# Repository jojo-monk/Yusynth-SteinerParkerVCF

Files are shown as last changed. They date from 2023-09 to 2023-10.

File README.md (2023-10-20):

# Yusynth-SteinerParkerVCF
Adaptation du Yusynth [SteinerParkerVCF](http://yusynth.net/Modular/index_en.html) au format Eurorack
Testé et Fonctionnel

J'ai fait une petite erreur sur la sérigraphie du bouton Mode qui se trouvait du mauvais côté du bouton, mais c'est corrigé dans le fichier kicad.
J'ai ajouté un trimmer 100k pour pouvoir régler la résonance.

I made a small mistake on the screen printing of the Mode button which was on the wrong side of the button, but it is corrected in the kicad file.
I added a 100k trimmer to be able to adjust the resonance.

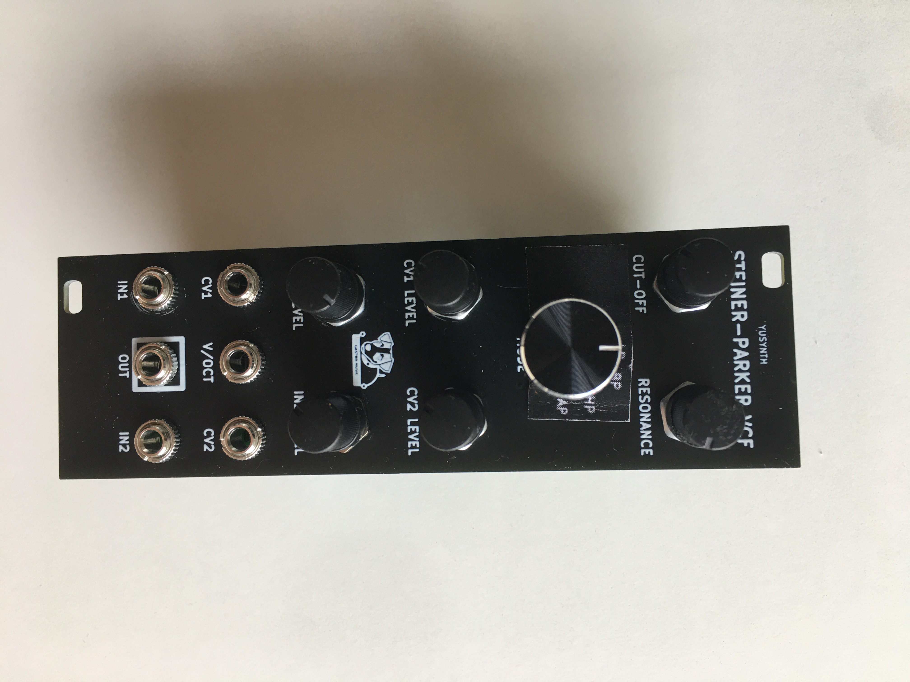
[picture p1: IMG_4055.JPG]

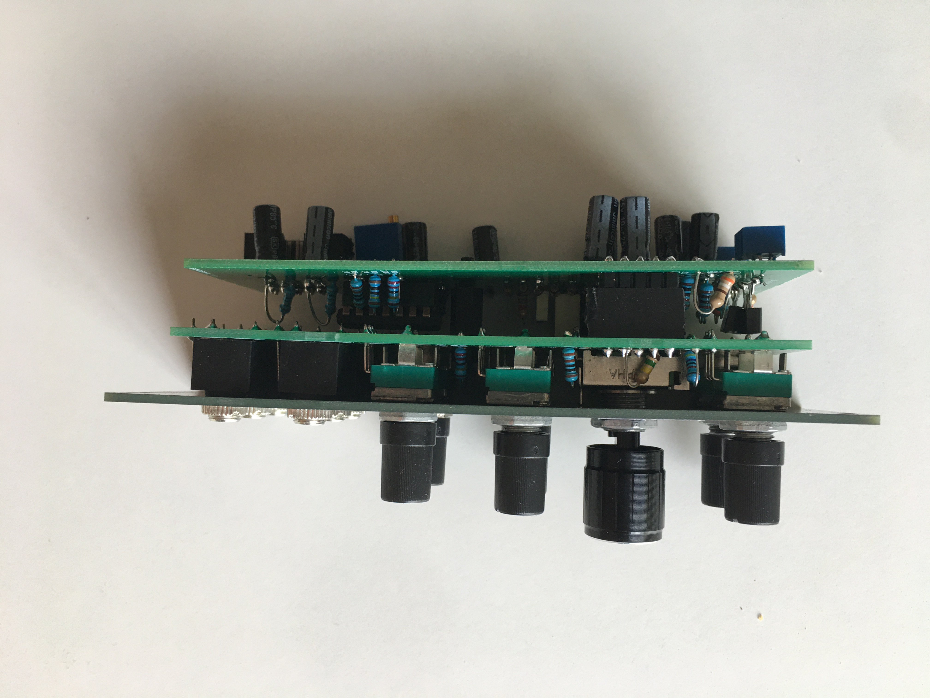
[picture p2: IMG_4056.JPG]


Remplacement de la resistance R19 de 3.9K par un trimpot 100K, (souder la 3eme patte sur la patte centrale)
Replacement of the 3.9K resistor R19 with a 100K trimpot, (solder the 3rd pin on the central pin).

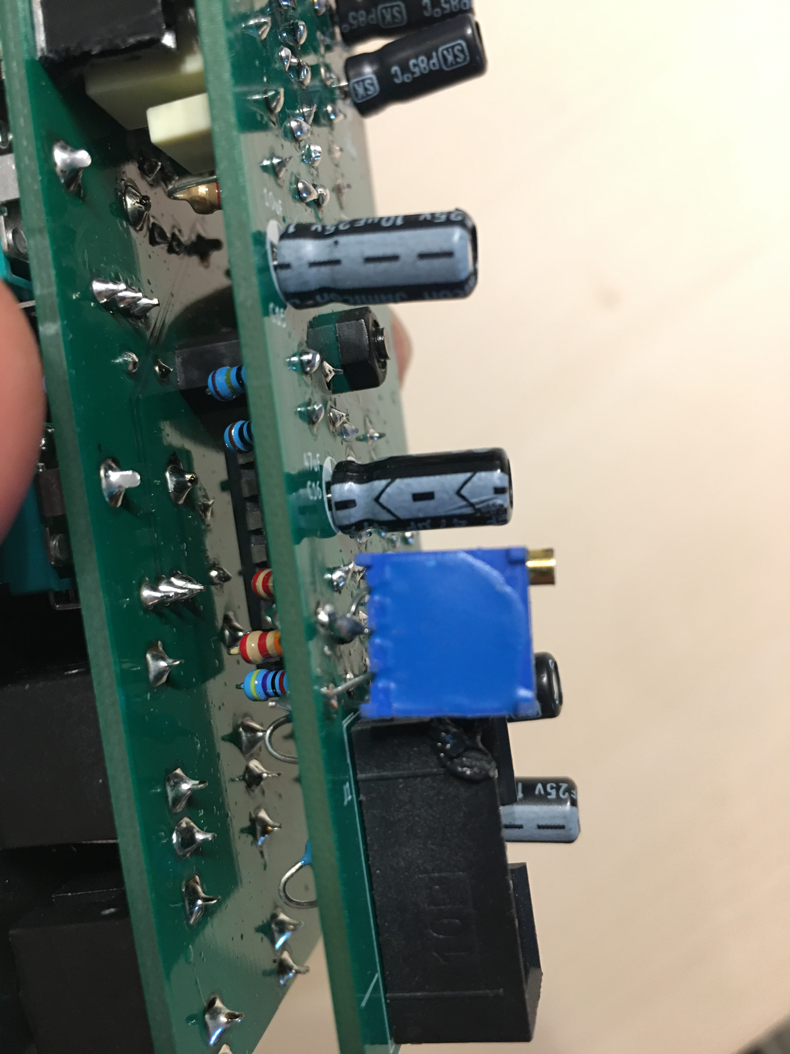
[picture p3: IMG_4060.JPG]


[Build document](https://htmlpreview.github.io/?https://github.com/jojo-monk/Yusynth-SteinerParkerVCF/blob/main/ibom.html)

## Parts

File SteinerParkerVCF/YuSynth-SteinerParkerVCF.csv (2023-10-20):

Source: | /Volumes/Stock/jojo/Documents/GitHub/Yusynth-SteinerParkerVCF/SteinerParkerVCF/YuSynth-SteinerParkerVCF.kicad_sch
Date: | Vendredi 20 octobre 2023 à 15:00:06
Tool: | Eeschema (6.0.11-0)
Generator: | /Applications/KiCad/KiCad.app/Contents/SharedSupport/plugins/bom_csv_grouped_by_value.py
Component Count: | 80
Individual Components:
Item | Qty | Reference(s) | Value | LibPart | Footprint | Datasheet | Datasheet_1 | Footprint_1 | Height | Manufacturer_Name | Manufacturer_Part_Number | Mouser Part Number | Mouser Price/Stock | Reference_1 | Value_1
 |  | 1111 | SR1712F-0204-20F0A-N9-N-027 | Alpha_Rotary_SW:SR1712F-0204-20F0A-N9-N-027 | Button_Switch_THT:SR1712F020420F0AN9N027 |  | https://componentsearchengine.com/Datasheets/1/SR1712F-0204-20F0A-N9-N-027.pdf | SR1712F020420F0AN9N027 | 27.5 | Alpha (Taiwan) | SR1712F-0204-20F0A-N9-N-027 | 105-SR1712F-24NS | https://www.mouser.co.uk/ProductDetail/Alpha-Taiwan/SR1712F-0204-20F0A-N9-N-027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 | S | Rotary-SW
 |  | C1 | 10uF | Device:C_Polarized | Capacitor_THT:CP_Radial_D5.0mm_P2.00mm | ~
 |  | C2 | 10uF | Device:C_Polarized | Capacitor_THT:CP_Radial_D5.0mm_P2.00mm | ~
 |  | C3 | 2.2uF | Device:C_Polarized | Capacitor_THT:CP_Radial_D5.0mm_P2.00mm | ~
 |  | C4 | 2.2uF | Device:C_Polarized | Capacitor_THT:CP_Radial_D5.0mm_P2.00mm | ~
 |  | C5 | 1.5nF | Device:C | Capacitor_THT:C_Rect_L7.0mm_W3.5mm_P5.00mm | ~
 |  | C6 | 47uF | Device:C_Polarized | Capacitor_THT:CP_Radial_D5.0mm_P2.00mm | ~
 |  | C7 | 1.5nF | Device:C | Capacitor_THT:C_Rect_L7.0mm_W3.5mm_P5.00mm | ~
 |  | C8 | 680nF | Device:C | Capacitor_THT:C_Rect_L7.0mm_W3.5mm_P5.00mm | ~
 |  | C9 | 47uF | Device:C_Polarized | Capacitor_THT:CP_Radial_D5.0mm_P2.00mm | ~
 |  | C10 | 1.5nF | Device:C | Capacitor_THT:C_Rect_L7.0mm_W3.5mm_P5.00mm | ~
 |  | C13 | 10uF | Device:C_Polarized | Capacitor_THT:CP_Radial_D5.0mm_P2.00mm | ~
 |  | C14 | 10uF | Device:C_Polarized | Capacitor_THT:CP_Radial_D5.0mm_P2.00mm | ~
 |  | C15 | 10uF | Device:C_Polarized | Capacitor_THT:CP_Radial_D5.0mm_P2.00mm | ~
 |  | C16 | 47uF | Device:C_Polarized | Capacitor_THT:CP_Radial_D5.0mm_P2.00mm | ~
 |  | D1 | 1N4148 | Diode:1N4148 | Diode_THT:D_DO-35_SOD27_P7.62mm_Horizontal | https://assets.nexperia.com/documents/data-sheet/1N4148_1N4448.pdf
 |  | D2 | 1N4148 | Diode:1N4148 | Diode_THT:D_DO-35_SOD27_P7.62mm_Horizontal | https://assets.nexperia.com/documents/data-sheet/1N4148_1N4448.pdf
 |  | D3 | 1N4148 | Diode:1N4148 | Diode_THT:D_DO-35_SOD27_P7.62mm_Horizontal | https://assets.nexperia.com/documents/data-sheet/1N4148_1N4448.pdf
 |  | D4 | 1N4148 | Diode:1N4148 | Diode_THT:D_DO-35_SOD27_P7.62mm_Horizontal | https://assets.nexperia.com/documents/data-sheet/1N4148_1N4448.pdf
 |  | D5 | 1N4148 | Diode:1N4148 | Diode_THT:D_DO-35_SOD27_P7.62mm_Horizontal | https://assets.nexperia.com/documents/data-sheet/1N4148_1N4448.pdf
 |  | D6 | 1N4148 | Diode:1N4148 | Diode_THT:D_DO-35_SOD27_P7.62mm_Horizontal | https://assets.nexperia.com/documents/data-sheet/1N4148_1N4448.pdf
 |  | D7 | 1N4148 | Diode:1N4148 | Diode_THT:D_DO-35_SOD27_P7.62mm_Horizontal | https://assets.nexperia.com/documents/data-sheet/1N4148_1N4448.pdf
 |  | D8 | 1N4148 | Diode:1N4148 | Diode_THT:D_DO-35_SOD27_P7.62mm_Horizontal | https://assets.nexperia.com/documents/data-sheet/1N4148_1N4448.pdf
 |  | D9 | 1N4148 | Diode:1N4148 | Diode_THT:D_DO-35_SOD27_P7.62mm_Horizontal | https://assets.nexperia.com/documents/data-sheet/1N4148_1N4448.pdf
 |  | D10 | 1N4148 | Diode:1N4148 | Diode_THT:D_DO-35_SOD27_P7.62mm_Horizontal | https://assets.nexperia.com/documents/data-sheet/1N4148_1N4448.pdf
 |  | H1 | MountingHole | Mechanical:MountingHole | MountingHole:MountingHole_3.2mm_M3 | ~
 |  | H2 | MountingHole | Mechanical:MountingHole | MountingHole:MountingHole_3.2mm_M3 | ~
 |  | J1 | EURO_PWR_2x5 | eurorack:EURO_PWR_2x5 | eurorack:Eurorack_power_header
 |  | J2 | CV1 | Connector:AudioJack2_SwitchT | Audio_Jack:Jack_3.5mm_QingPu_WQP-PJ398SM_Vertical | ~
 |  | J3 | CV2 | Connector:AudioJack2_SwitchT | Audio_Jack:Jack_3.5mm_QingPu_WQP-PJ398SM_Vertical | ~
 |  | J4 | V/OCT | Connector:AudioJack2_SwitchT | Audio_Jack:Jack_3.5mm_QingPu_WQP-PJ398SM_Vertical | ~
 |  | J5 | IN1 | Connector:AudioJack2_SwitchT | Audio_Jack:Jack_3.5mm_QingPu_WQP-PJ398SM_Vertical | ~
 |  | J6 | IN2 | Connector:AudioJack2_SwitchT | Audio_Jack:Jack_3.5mm_QingPu_WQP-PJ398SM_Vertical | ~
 |  | J7 | Conn_01x05_Female | Connector:Conn_01x05_Female | Connector_PinHeader_2.54mm:PinHeader_1x05_P2.54mm_Vertical | ~
 |  | J8 | Conn_01x08_Female | Connector:Conn_01x08_Female | Connector_PinHeader_2.54mm:PinHeader_1x08_P2.54mm_Vertical | ~
 |  | J9 | OUT | Connector:AudioJack2_SwitchT | Audio_Jack:Jack_3.5mm_QingPu_WQP-PJ398SM_Vertical | ~
 |  | J10 | Conn_01x08_Female | Connector:Conn_01x08_Female | Connector_PinHeader_2.54mm:PinHeader_1x08_P2.54mm_Vertical | ~
 |  | J11 | Conn_01x05_Male | Connector:Conn_01x05_Male | Connector_PinHeader_2.54mm:PinHeader_1x05_P2.54mm_Vertical | ~
 |  | Q1 | BC547 | Transistor_BJT:BC547 | Package_TO_SOT_THT:TO-92_HandSolder | https://www.onsemi.com/pub/Collateral/BC550-D.pdf
 |  | Q2 | BC547 | Transistor_BJT:BC547 | Package_TO_SOT_THT:TO-92_HandSolder | https://www.onsemi.com/pub/Collateral/BC550-D.pdf
 |  | R1 | 220 | Device:R | Resistor_THT:R_Axial_DIN0207_L6.3mm_D2.5mm_P5.08mm_Vertical | ~
 |  | R2 | 10K | Device:R | Resistor_THT:R_Axial_DIN0207_L6.3mm_D2.5mm_P5.08mm_Vertical | ~
 |  | R3 | 10K | Device:R | Resistor_THT:R_Axial_DIN0207_L6.3mm_D2.5mm_P5.08mm_Vertical | ~
 |  | R4 | 10K | Device:R | Resistor_THT:R_Axial_DIN0207_L6.3mm_D2.5mm_P5.08mm_Vertical | ~
 |  | R5 | 1.8K | Device:R | Resistor_THT:R_Axial_DIN0207_L6.3mm_D2.5mm_P5.08mm_Vertical | ~
 |  | R6 | 3.9K | Device:R | Resistor_THT:R_Axial_DIN0207_L6.3mm_D2.5mm_P5.08mm_Vertical | ~
 |  | R7 | 82 | Device:R | Resistor_THT:R_Axial_DIN0207_L6.3mm_D2.5mm_P5.08mm_Vertical | ~
 |  | R8 | 1K | Device:R | Resistor_THT:R_Axial_DIN0207_L6.3mm_D2.5mm_P5.08mm_Vertical | ~
 |  | R9 | 390 | Device:R | Resistor_THT:R_Axial_DIN0207_L6.3mm_D2.5mm_P5.08mm_Vertical | ~
 |  | R10 | 1.8K | Device:R | Resistor_THT:R_Axial_DIN0207_L6.3mm_D2.5mm_P5.08mm_Vertical | ~
 |  | R11 | 1K | Device:R | Resistor_THT:R_Axial_DIN0207_L6.3mm_D2.5mm_P5.08mm_Vertical | ~
 |  | R12 | 2.2M | Device:R | Resistor_THT:R_Axial_DIN0207_L6.3mm_D2.5mm_P5.08mm_Vertical | ~
 |  | R13 | 22K | Device:R | Resistor_THT:R_Axial_DIN0207_L6.3mm_D2.5mm_P5.08mm_Vertical | ~
 |  | R14 | 1M | Device:R | Resistor_THT:R_Axial_DIN0207_L6.3mm_D2.5mm_P5.08mm_Vertical | ~
 |  | R15 | 220K | Device:R | Resistor_THT:R_Axial_DIN0207_L6.3mm_D2.5mm_P5.08mm_Vertical | ~
 |  | R16 | 47K | Device:R | Resistor_THT:R_Axial_DIN0207_L6.3mm_D2.5mm_P5.08mm_Vertical | ~
 |  | R17 | 10 | Device:R | Resistor_THT:R_Axial_DIN0207_L6.3mm_D2.5mm_P5.08mm_Vertical | ~
 |  | R18 | 10 | Device:R | Resistor_THT:R_Axial_DIN0207_L6.3mm_D2.5mm_P5.08mm_Vertical | ~
 |  | R20 | 10K | Device:R | Resistor_THT:R_Axial_DIN0207_L6.3mm_D2.5mm_P5.08mm_Vertical | ~
 |  | R21 | 220K | Device:R | Resistor_THT:R_Axial_DIN0207_L6.3mm_D2.5mm_P5.08mm_Vertical | ~
 |  | R22 | 220K | Device:R | Resistor_THT:R_Axial_DIN0207_L6.3mm_D2.5mm_P5.08mm_Vertical | ~
 |  | R23 | 220K | Device:R | Resistor_THT:R_Axial_DIN0207_L6.3mm_D2.5mm_P5.08mm_Vertical | ~
 |  | R24 | 47K | Device:R | Resistor_THT:R_Axial_DIN0207_L6.3mm_D2.5mm_P5.08mm_Vertical | ~
 |  | R25 | 150K | Device:R | Resistor_THT:R_Axial_DIN0207_L6.3mm_D2.5mm_P5.08mm_Vertical | ~
 |  | R26 | 220K | Device:R | Resistor_THT:R_Axial_DIN0207_L6.3mm_D2.5mm_P5.08mm_Vertical | ~
 |  | R27 | 1K | Device:R | Resistor_THT:R_Axial_DIN0207_L6.3mm_D2.5mm_P5.08mm_Vertical | ~
 |  | R28 | 47K | Device:R | Resistor_THT:R_Axial_DIN0207_L6.3mm_D2.5mm_P5.08mm_Vertical | ~
 |  | R29 | 1K | Device:R | Resistor_THT:R_Axial_DIN0207_L6.3mm_D2.5mm_P5.08mm_Vertical | ~
 |  | R30 | 180K | Device:R | Resistor_THT:R_Axial_DIN0207_L6.3mm_D2.5mm_P5.08mm_Vertical | ~
 |  | R31 | 180K | Device:R | Resistor_THT:R_Axial_DIN0207_L6.3mm_D2.5mm_P5.08mm_Vertical | ~
 |  | RV1 | 2K | Device:R_Potentiometer_Trim | Potentiometer_THT:Potentiometer_Bourns_3266Y_Vertical | ~
 |  | RV2 | 1K | Device:R_Potentiometer_Trim | Potentiometer_THT:Potentiometer_Bourns_3266Y_Vertical | ~
 |  | RV3 | IN 47K Log | Device:R_Potentiometer | Potentiometer_THT:Potentiometer_Alpha_RD901F-40-00D_Single_Vertical | ~
 |  | RV4 | IN 47K Log | Device:R_Potentiometer | Potentiometer_THT:Potentiometer_Alpha_RD901F-40-00D_Single_Vertical | ~
 |  | RV5 | CV1 47K LIN | Device:R_Potentiometer | Potentiometer_THT:Potentiometer_Alpha_RD901F-40-00D_Single_Vertical | ~
 |  | RV6 | CV2 47K LIN | Device:R_Potentiometer | Potentiometer_THT:Potentiometer_Alpha_RD901F-40-00D_Single_Vertical | ~
 |  | RV7 | CUT-OFF 47K LIN | Device:R_Potentiometer | Potentiometer_THT:Potentiometer_Alpha_RD901F-40-00D_Single_Vertical | ~
 |  | RV8 | RESONANCE 50K REV-AUDIO | Device:R_Potentiometer | Potentiometer_THT:Potentiometer_Alpha_RD901F-40-00D_Single_Vertical | ~
 |  | RV9 | 100K | Device:R_Potentiometer_Trim | Potentiometer_THT:Potentiometer_Bourns_3266Y_Vertical | ~
 |  | U1 | TL074 | Amplifier_Operational:TL074 | Package_DIP:DIP-14_W7.62mm_LongPads | http://www.ti.com/lit/ds/symlink/tl071.pdf
Collated Components:
Item | Qty | Reference(s) | Value | LibPart | Footprint | Datasheet | Datasheet_1 | Footprint_1 | Height | Manufacturer_Name | Manufacturer_Part_Number | Mouser Part Number | Mouser Price/Stock | Reference_1 | Value_1
1 | 1 | 1111 | SR1712F-0204-20F0A-N9-N-027 | Alpha_Rotary_SW:SR1712F-0204-20F0A-N9-N-027 | Button_Switch_THT:SR1712F020420F0AN9N027 |  | https://componentsearchengine.com/Datasheets/1/SR1712F-0204-20F0A-N9-N-027.pdf | SR1712F020420F0AN9N027 | 27.5 | Alpha (Taiwan) | SR1712F-0204-20F0A-N9-N-027 | 105-SR1712F-24NS | https://www.mouser.co.uk/ProductDetail/Alpha-Taiwan/SR1712F-0204-20F0A-N9-N-027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 | S | Rotary-SW
2 | 5 | C1, C2, C13, C14, C15 | 10uF | Device:C_Polarized | Capacitor_THT:CP_Radial_D5.0mm_P2.00mm | ~
3 | 2 | C3, C4 | 2.2uF | Device:C_Polarized | Capacitor_THT:CP_Radial_D5.0mm_P2.00mm | ~
4 | 3 | C5, C7, C10 | 1.5nF | Device:C | Capacitor_THT:C_Rect_L7.0mm_W3.5mm_P5.00mm | ~
5 | 3 | C6, C9, C16 | 47uF | Device:C_Polarized | Capacitor_THT:CP_Radial_D5.0mm_P2.00mm | ~
6 | 1 | C8 | 680nF | Device:C | Capacitor_THT:C_Rect_L7.0mm_W3.5mm_P5.00mm | ~
7 | 10 | D1, D2, D3, D4, D5, D6, D7, D8, D9, D10 | 1N4148 | Diode:1N4148 | Diode_THT:D_DO-35_SOD27_P7.62mm_Horizontal | https://assets.nexperia.com/documents/data-sheet/1N4148_1N4448.pdf
8 | 2 | H1, H2 | MountingHole | Mechanical:MountingHole | MountingHole:MountingHole_3.2mm_M3 | ~
9 | 1 | J1 | EURO_PWR_2x5 | eurorack:EURO_PWR_2x5 | eurorack:Eurorack_power_header
10 | 1 | J2 | CV1 | Connector:AudioJack2_SwitchT | Audio_Jack:Jack_3.5mm_QingPu_WQP-PJ398SM_Vertical | ~
11 | 1 | J3 | CV2 | Connector:AudioJack2_SwitchT | Audio_Jack:Jack_3.5mm_QingPu_WQP-PJ398SM_Vertical | ~
12 | 1 | J4 | V/OCT | Connector:AudioJack2_SwitchT | Audio_Jack:Jack_3.5mm_QingPu_WQP-PJ398SM_Vertical | ~
13 | 1 | J5 | IN1 | Connector:AudioJack2_SwitchT | Audio_Jack:Jack_3.5mm_QingPu_WQP-PJ398SM_Vertical | ~
14 | 1 | J6 | IN2 | Connector:AudioJack2_SwitchT | Audio_Jack:Jack_3.5mm_QingPu_WQP-PJ398SM_Vertical | ~
15 | 1 | J7 | Conn_01x05_Female | Connector:Conn_01x05_Female | Connector_PinHeader_2.54mm:PinHeader_1x05_P2.54mm_Vertical | ~
16 | 2 | J8, J10 | Conn_01x08_Female | Connector:Conn_01x08_Female | Connector_PinHeader_2.54mm:PinHeader_1x08_P2.54mm_Vertical | ~
17 | 1 | J9 | OUT | Connector:AudioJack2_SwitchT | Audio_Jack:Jack_3.5mm_QingPu_WQP-PJ398SM_Vertical | ~
18 | 1 | J11 | Conn_01x05_Male | Connector:Conn_01x05_Male | Connector_PinHeader_2.54mm:PinHeader_1x05_P2.54mm_Vertical | ~
19 | 2 | Q1, Q2 | BC547 | Transistor_BJT:BC547 | Package_TO_SOT_THT:TO-92_HandSolder | https://www.onsemi.com/pub/Collateral/BC550-D.pdf
20 | 1 | R1 | 220 | Device:R | Resistor_THT:R_Axial_DIN0207_L6.3mm_D2.5mm_P5.08mm_Vertical | ~
21 | 4 | R2, R3, R4, R20 | 10K | Device:R | Resistor_THT:R_Axial_DIN0207_L6.3mm_D2.5mm_P5.08mm_Vertical | ~
22 | 2 | R5, R10 | 1.8K | Device:R | Resistor_THT:R_Axial_DIN0207_L6.3mm_D2.5mm_P5.08mm_Vertical | ~
23 | 1 | R6 | 3.9K | Device:R | Resistor_THT:R_Axial_DIN0207_L6.3mm_D2.5mm_P5.08mm_Vertical | ~
24 | 1 | R7 | 82 | Device:R | Resistor_THT:R_Axial_DIN0207_L6.3mm_D2.5mm_P5.08mm_Vertical | ~
25 | 4 | R8, R11, R27, R29 | 1K | Device:R | Resistor_THT:R_Axial_DIN0207_L6.3mm_D2.5mm_P5.08mm_Vertical | ~
26 | 1 | R9 | 390 | Device:R | Resistor_THT:R_Axial_DIN0207_L6.3mm_D2.5mm_P5.08mm_Vertical | ~
27 | 1 | R12 | 2.2M | Device:R | Resistor_THT:R_Axial_DIN0207_L6.3mm_D2.5mm_P5.08mm_Vertical | ~
28 | 1 | R13 | 22K | Device:R | Resistor_THT:R_Axial_DIN0207_L6.3mm_D2.5mm_P5.08mm_Vertical | ~
29 | 1 | R14 | 1M | Device:R | Resistor_THT:R_Axial_DIN0207_L6.3mm_D2.5mm_P5.08mm_Vertical | ~
30 | 5 | R15, R21, R22, R23, R26 | 220K | Device:R | Resistor_THT:R_Axial_DIN0207_L6.3mm_D2.5mm_P5.08mm_Vertical | ~
31 | 3 | R16, R24, R28 | 47K | Device:R | Resistor_THT:R_Axial_DIN0207_L6.3mm_D2.5mm_P5.08mm_Vertical | ~
32 | 2 | R17, R18 | 10 | Device:R | Resistor_THT:R_Axial_DIN0207_L6.3mm_D2.5mm_P5.08mm_Vertical | ~
33 | 1 | R25 | 150K | Device:R | Resistor_THT:R_Axial_DIN0207_L6.3mm_D2.5mm_P5.08mm_Vertical | ~
34 | 2 | R30, R31 | 180K | Device:R | Resistor_THT:R_Axial_DIN0207_L6.3mm_D2.5mm_P5.08mm_Vertical | ~
35 | 1 | RV1 | 2K | Device:R_Potentiometer_Trim | Potentiometer_THT:Potentiometer_Bourns_3266Y_Vertical | ~
36 | 1 | RV2 | 1K | Device:R_Potentiometer_Trim | Potentiometer_THT:Potentiometer_Bourns_3266Y_Vertical | ~
37 | 2 | RV3, RV4 | IN 47K Log | Device:R_Potentiometer | Potentiometer_THT:Potentiometer_Alpha_RD901F-40-00D_Single_Vertical | ~
38 | 1 | RV5 | CV1 47K LIN | Device:R_Potentiometer | Potentiometer_THT:Potentiometer_Alpha_RD901F-40-00D_Single_Vertical | ~
39 | 1 | RV6 | CV2 47K LIN | Device:R_Potentiometer | Potentiometer_THT:Potentiometer_Alpha_RD901F-40-00D_Single_Vertical | ~
40 | 1 | RV7 | CUT-OFF 47K LIN | Device:R_Potentiometer | Potentiometer_THT:Potentiometer_Alpha_RD901F-40-00D_Single_Vertical | ~
41 | 1 | RV8 | RESONANCE 50K REV-AUDIO | Device:R_Potentiometer | Potentiometer_THT:Potentiometer_Alpha_RD901F-40-00D_Single_Vertical | ~
42 | 1 | RV9 | 100K | Device:R_Potentiometer_Trim | Potentiometer_THT:Potentiometer_Bourns_3266Y_Vertical | ~
43 | 1 | U1 | TL074 | Amplifier_Operational:TL074 | Package_DIP:DIP-14_W7.62mm_LongPads | http://www.ti.com/lit/ds/symlink/tl071.pdf

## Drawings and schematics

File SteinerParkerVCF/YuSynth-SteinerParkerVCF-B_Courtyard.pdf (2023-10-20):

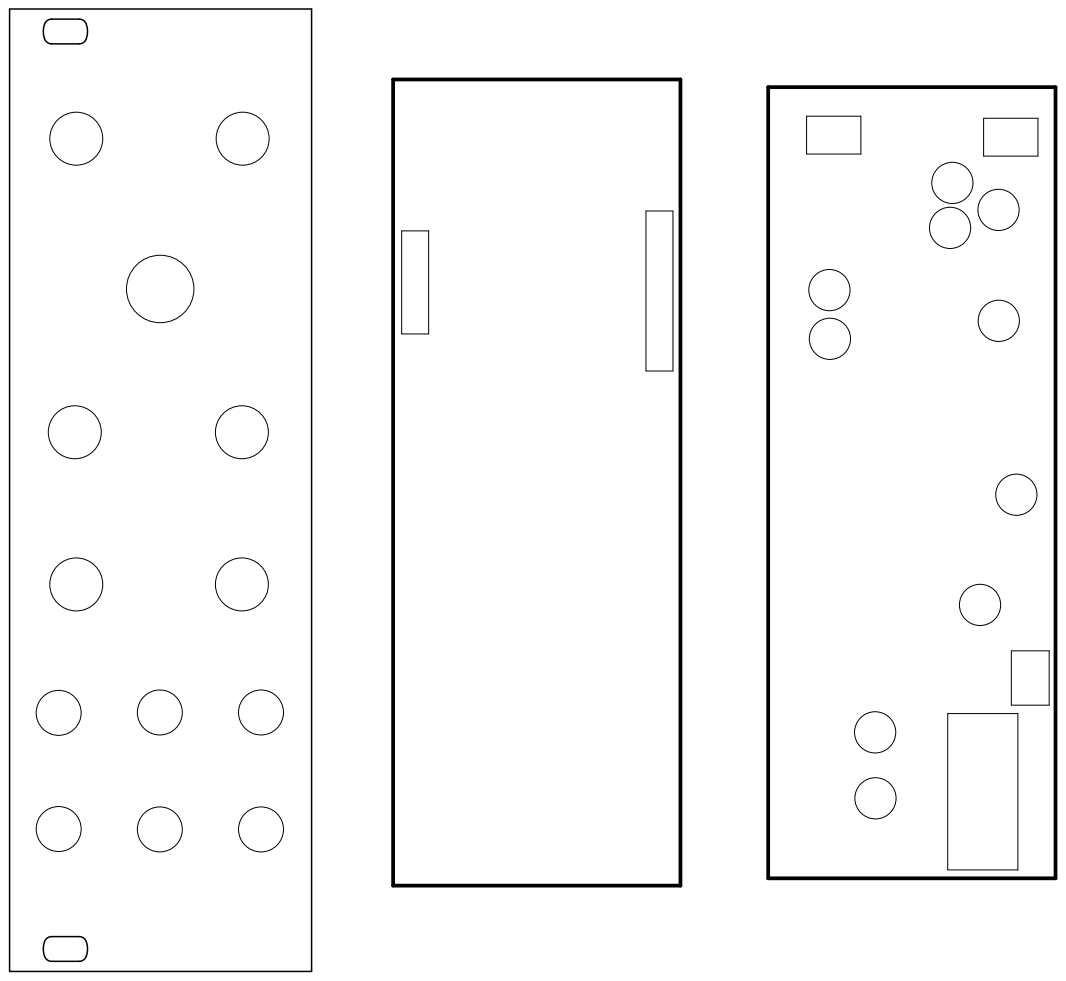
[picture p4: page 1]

Id: 1/1 Title: File: YuSynth-SteinerParkerVCF.kicad_pcb Sheet:

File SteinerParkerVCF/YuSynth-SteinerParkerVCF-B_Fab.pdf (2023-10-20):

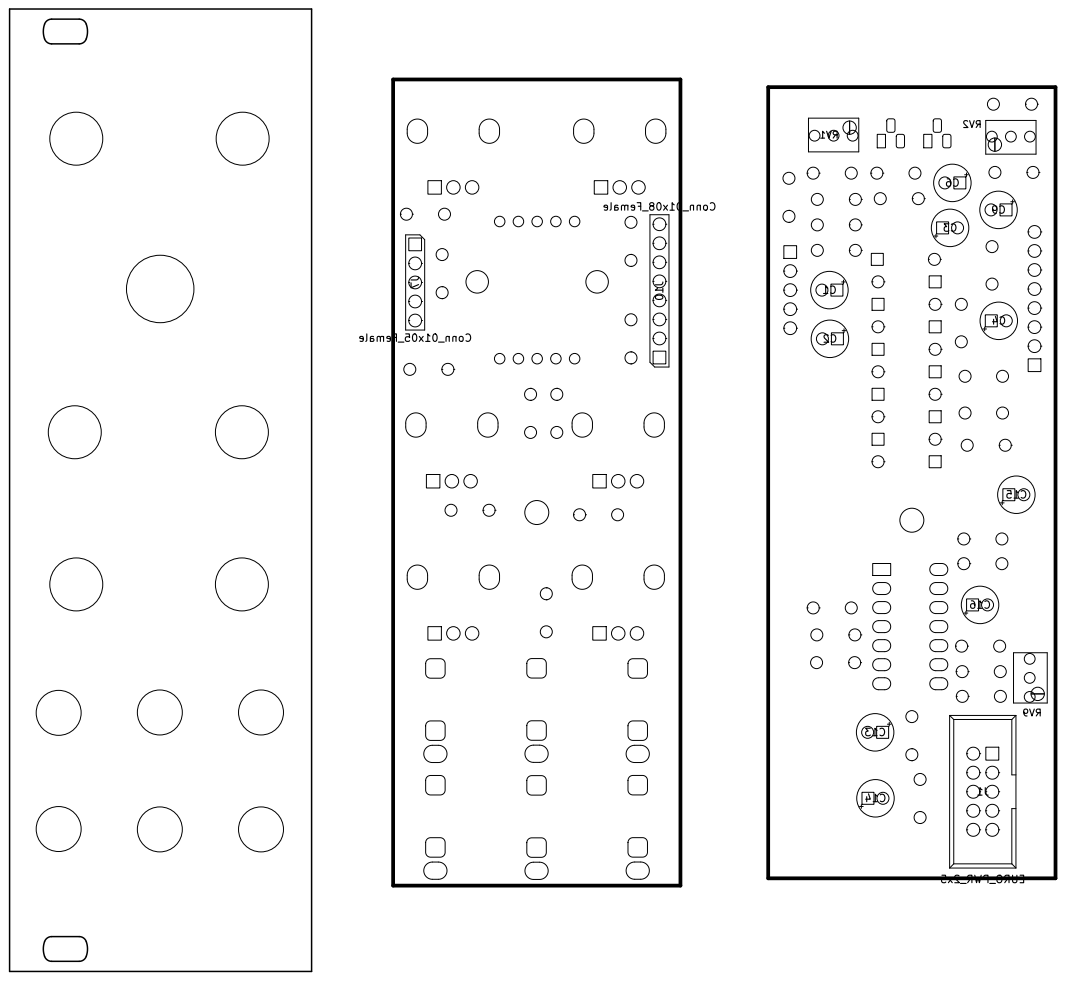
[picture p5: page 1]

Id: 1/1 Title: File: YuSynth-SteinerParkerVCF.kicad_pcb Sheet:

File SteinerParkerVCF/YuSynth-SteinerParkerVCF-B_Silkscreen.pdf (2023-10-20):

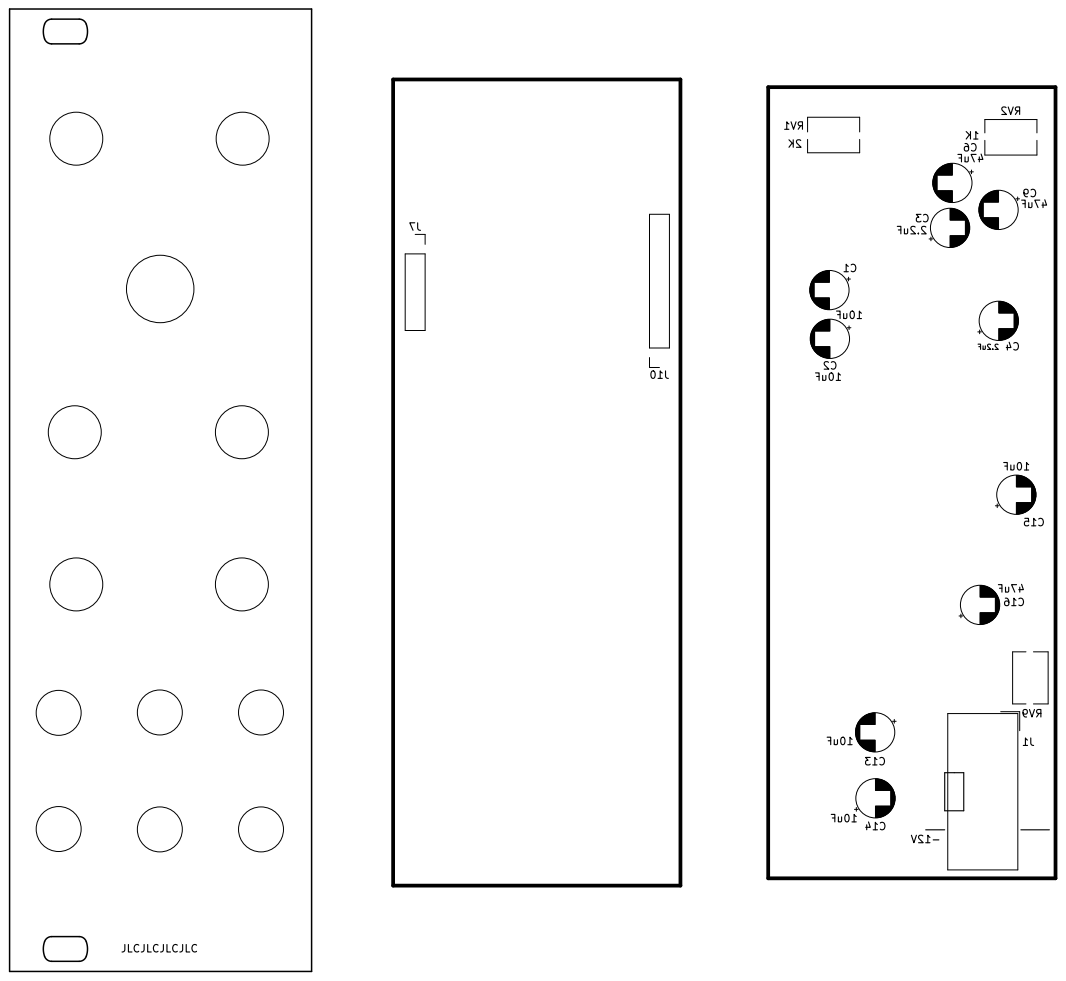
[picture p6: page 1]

Id: 1/1 Title: File: YuSynth-SteinerParkerVCF.kicad_pcb Sheet: JLCJLCJLCJLC

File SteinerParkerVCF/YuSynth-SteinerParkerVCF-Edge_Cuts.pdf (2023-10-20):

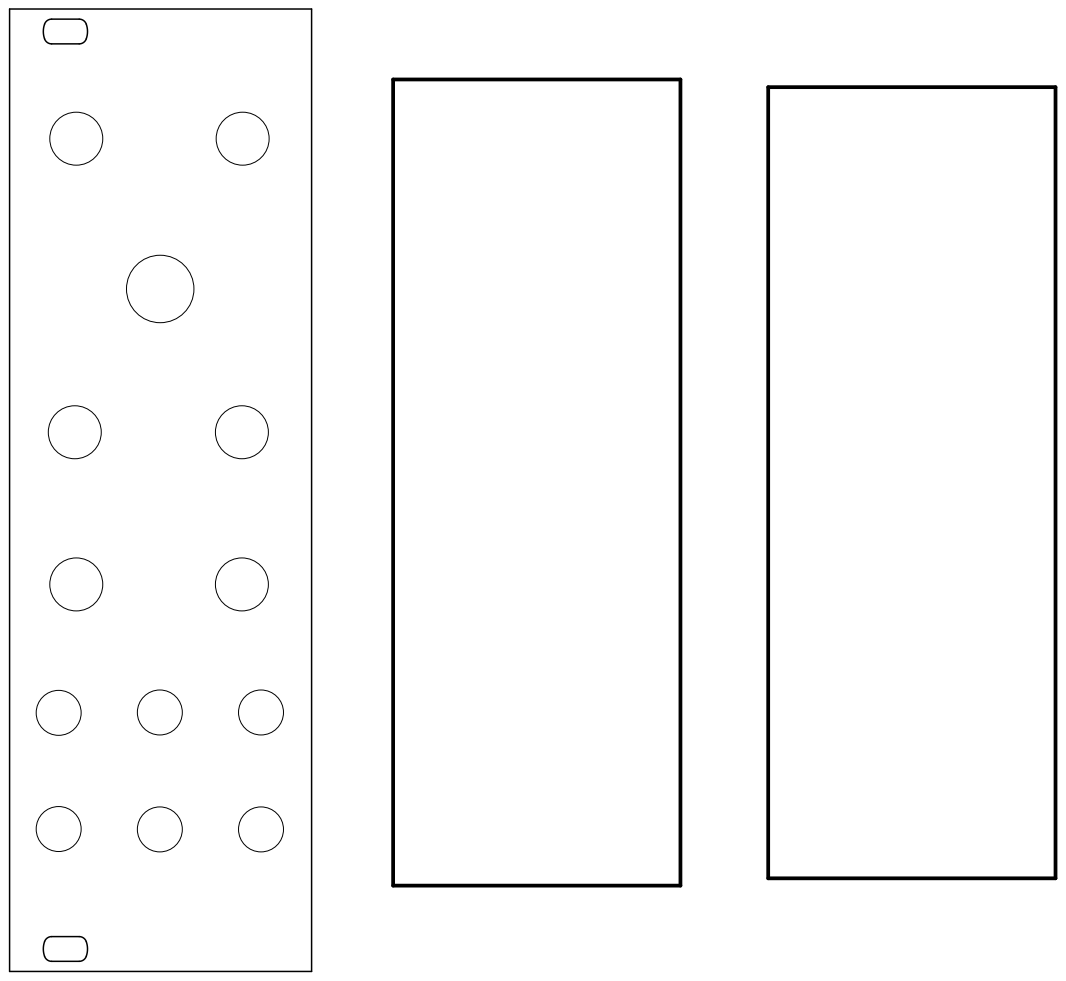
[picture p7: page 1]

Id: 1/1 Title: File: YuSynth-SteinerParkerVCF.kicad_pcb Sheet:

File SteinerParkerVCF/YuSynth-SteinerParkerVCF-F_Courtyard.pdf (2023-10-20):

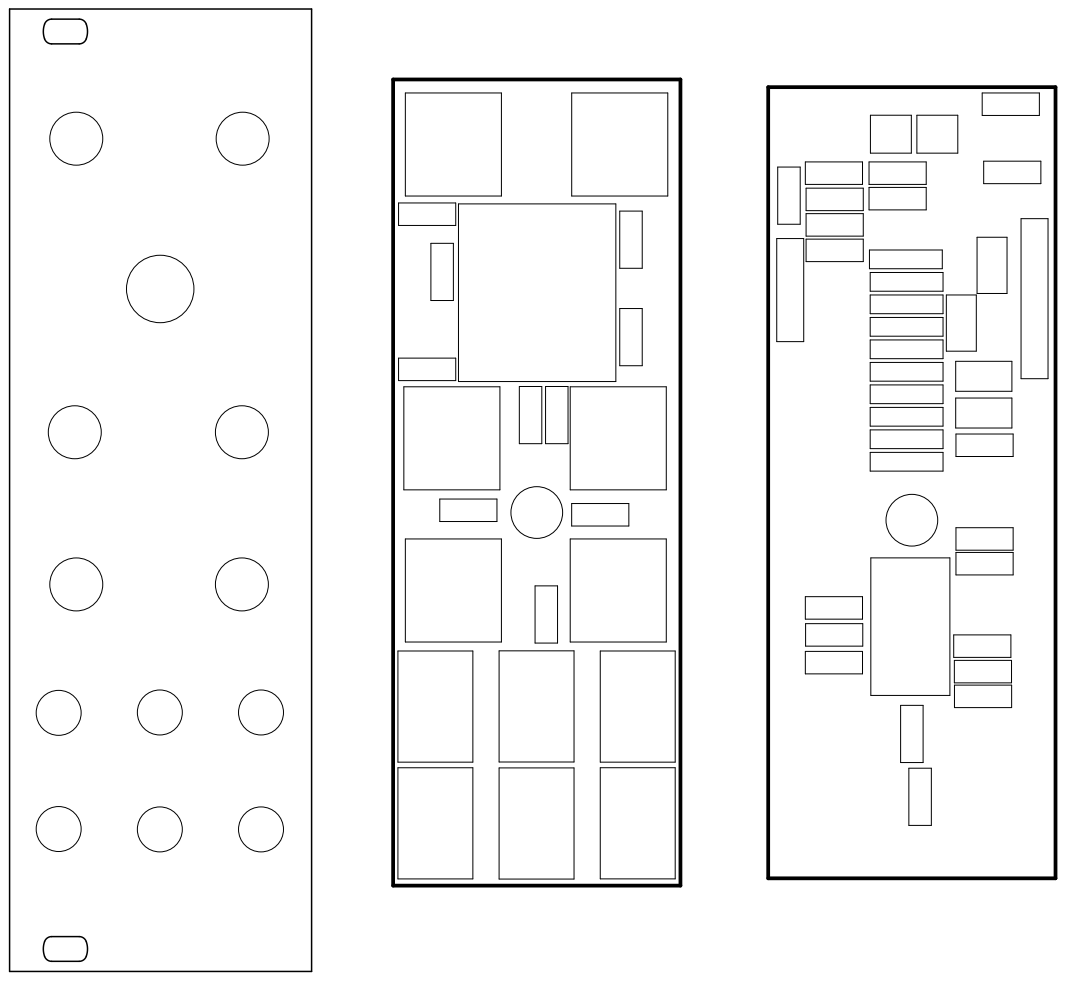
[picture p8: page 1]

Id: 1/1 Title: File: YuSynth-SteinerParkerVCF.kicad_pcb Sheet:

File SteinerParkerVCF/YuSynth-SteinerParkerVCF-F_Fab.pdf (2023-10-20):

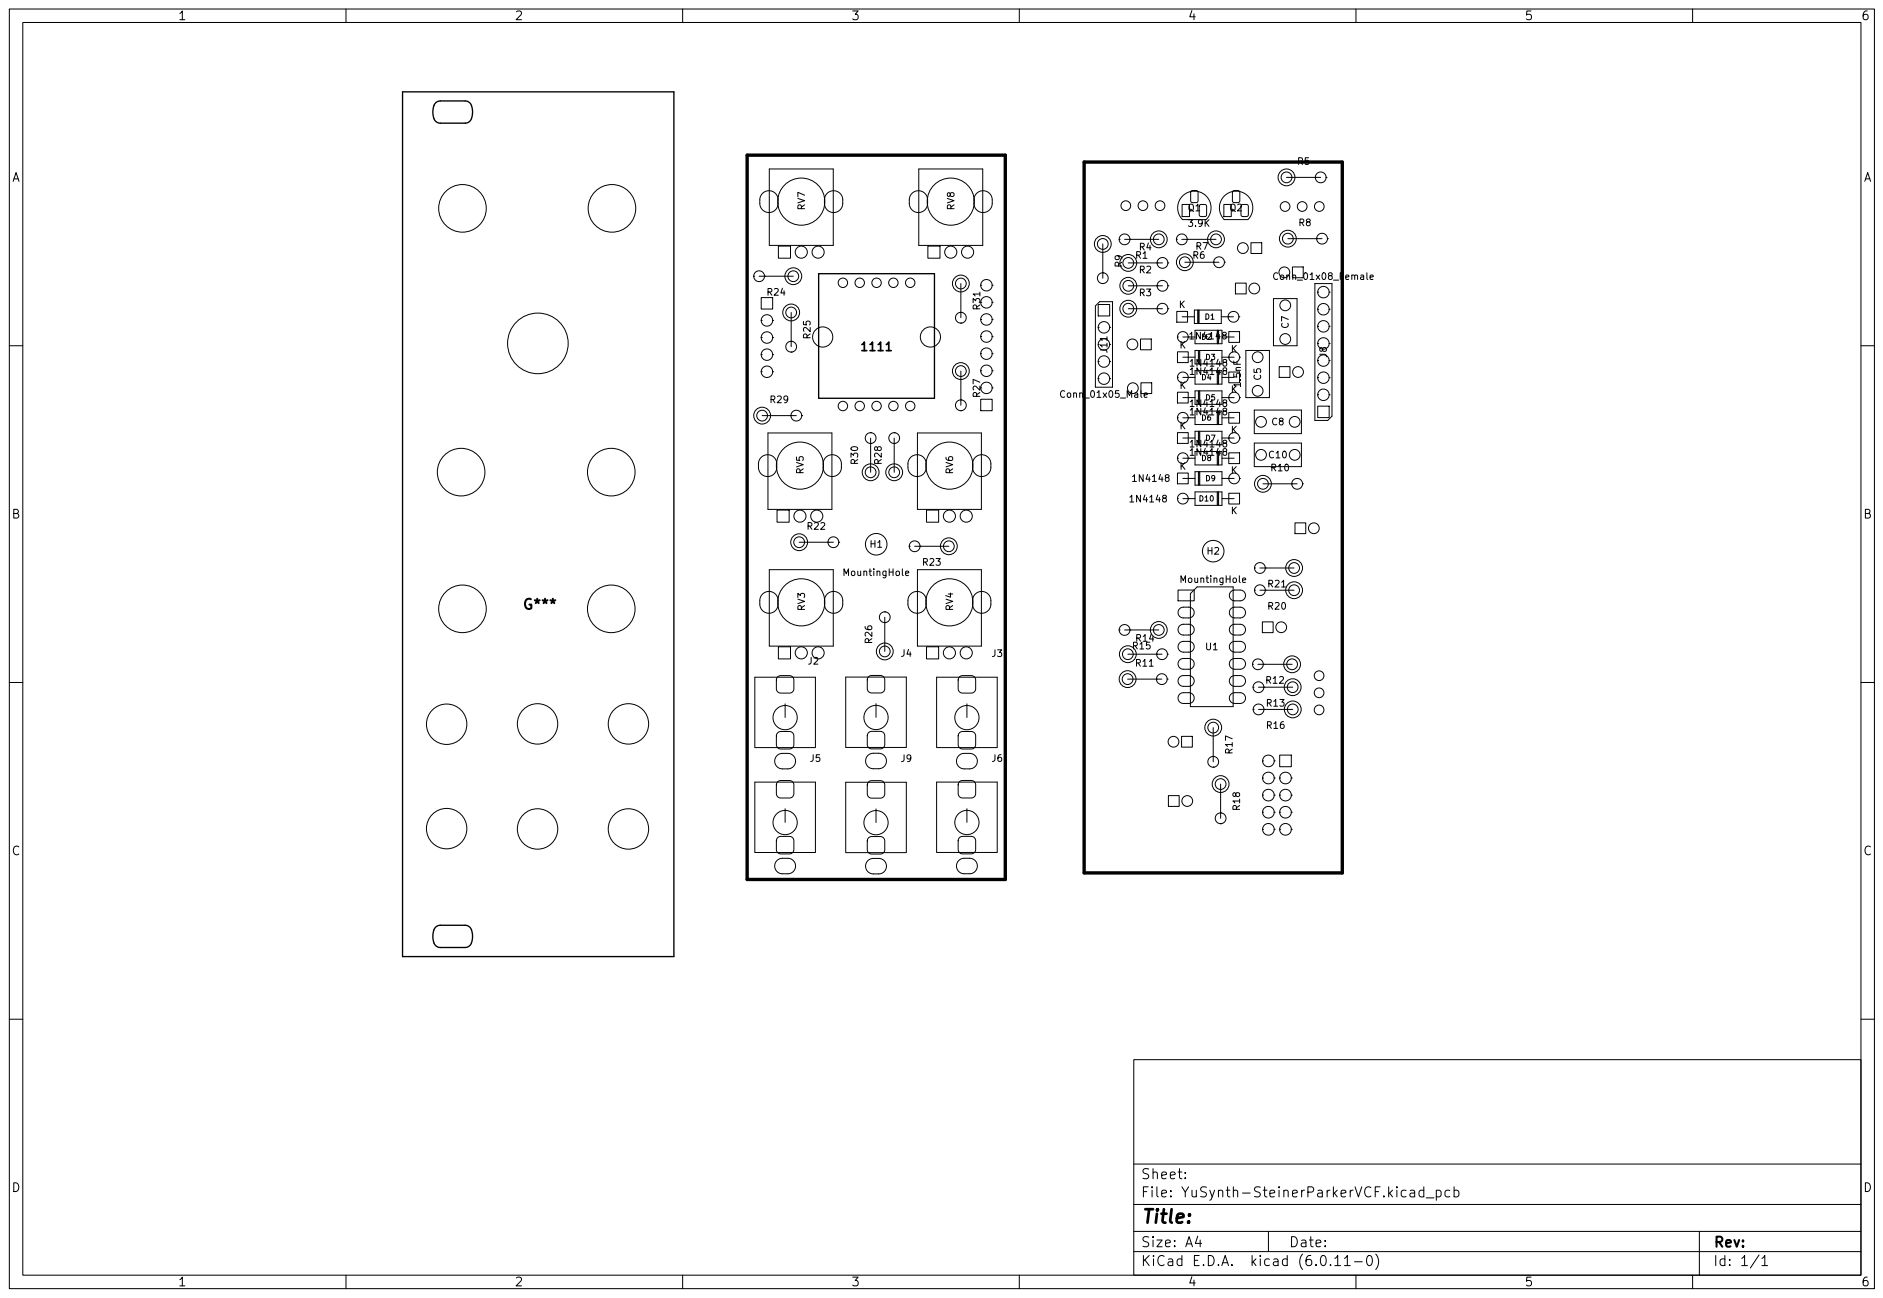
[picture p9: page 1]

Id: 1/1 Title: File: YuSynth-SteinerParkerVCF.kicad_pcb Sheet: G***

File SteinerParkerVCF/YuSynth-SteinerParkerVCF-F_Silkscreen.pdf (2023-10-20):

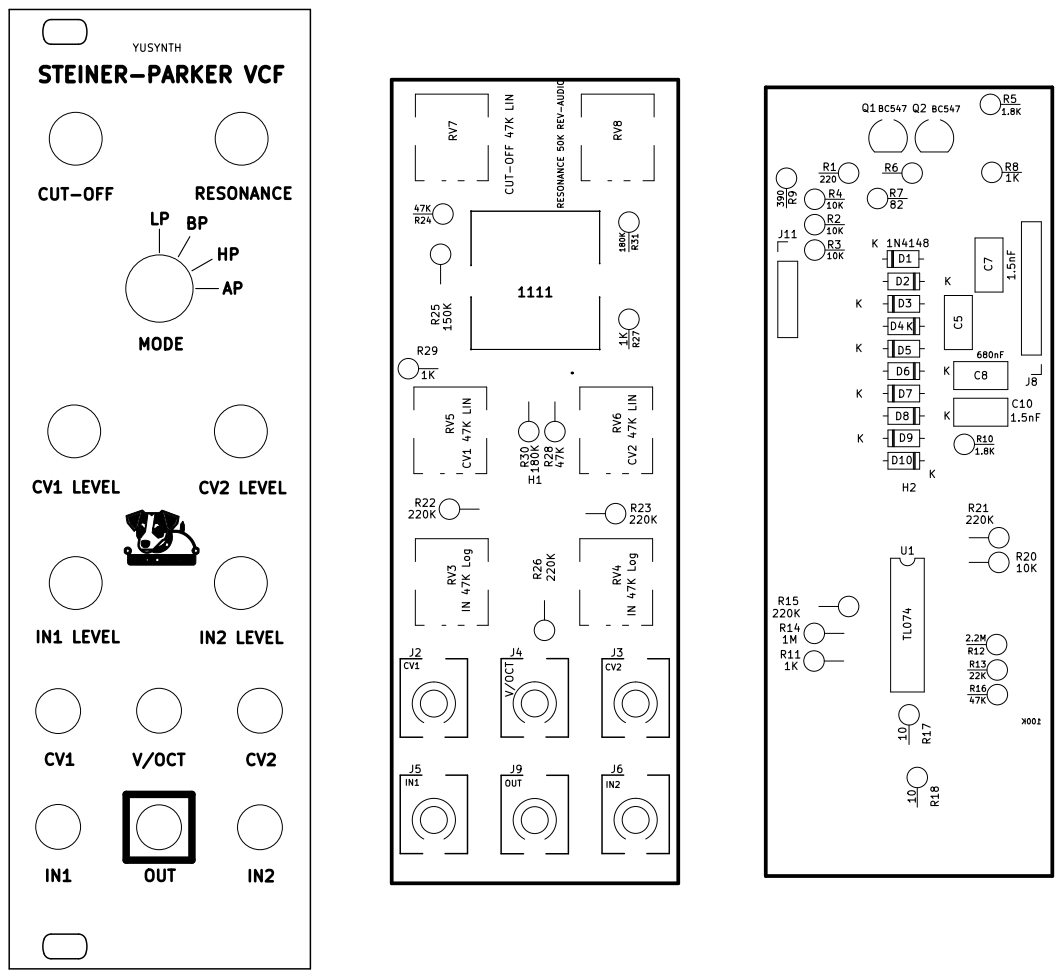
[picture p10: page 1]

Id: 1/1 Title: File: YuSynth-SteinerParkerVCF.kicad_pcb Sheet:

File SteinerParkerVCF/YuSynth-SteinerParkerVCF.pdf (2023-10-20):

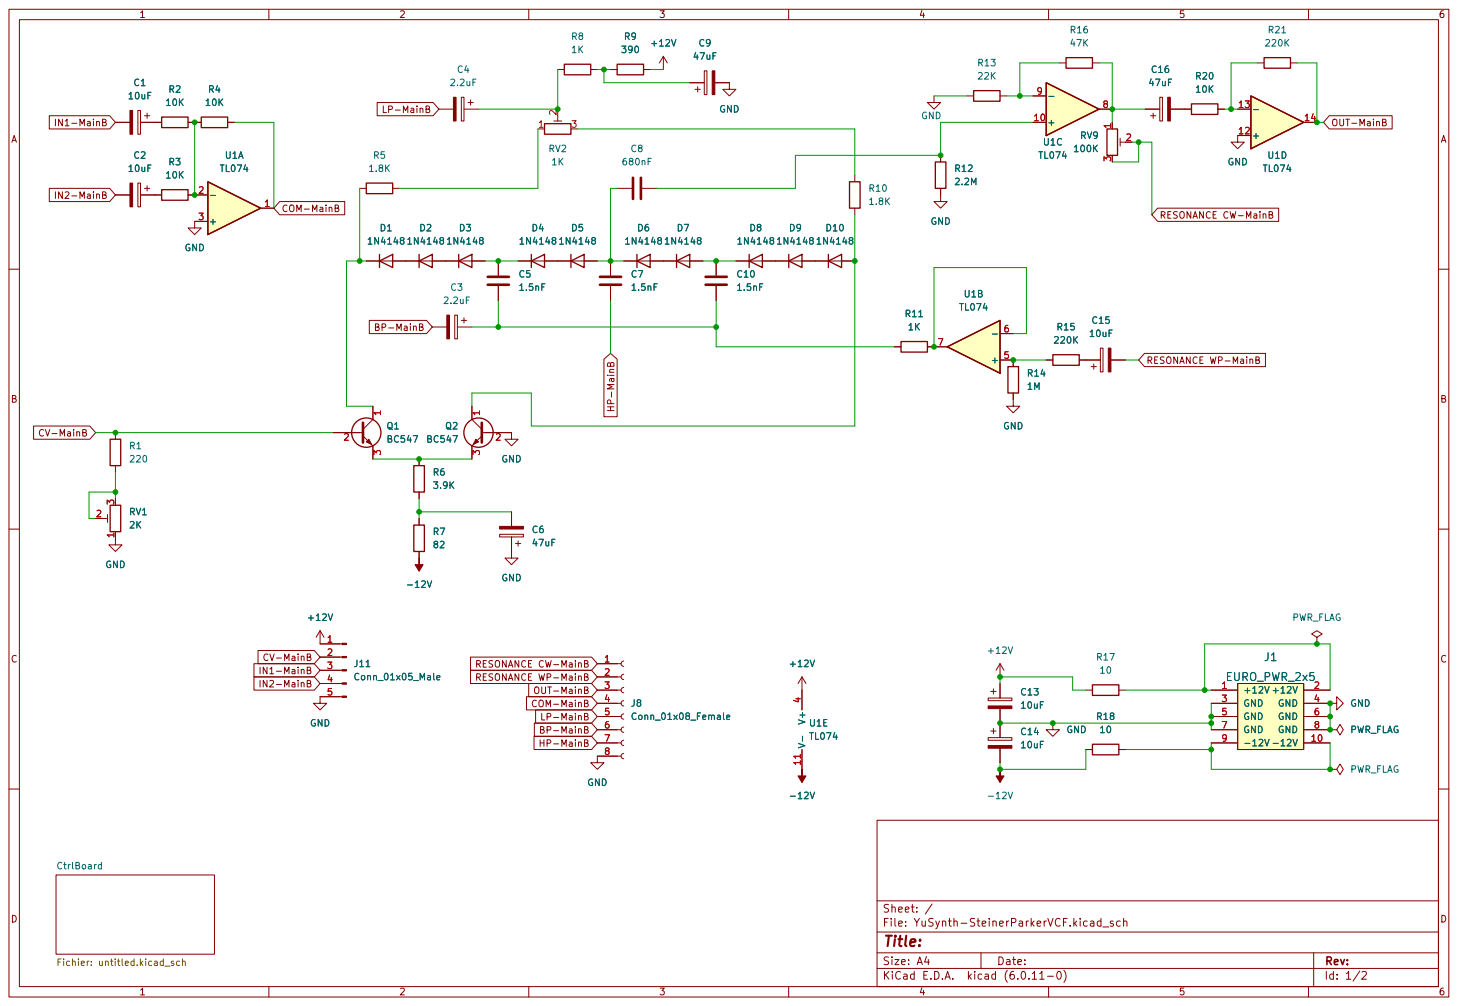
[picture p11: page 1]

LP-MainB COM-MainB

1N4148 RESONANCE WP-MainB RESONANCE CW-MainB

Id: 1/2 Title: File: YuSynth-SteinerParkerVCF.kicad_sch Sheet: / CtrlBoard Fichier: untitled.kicad_sch

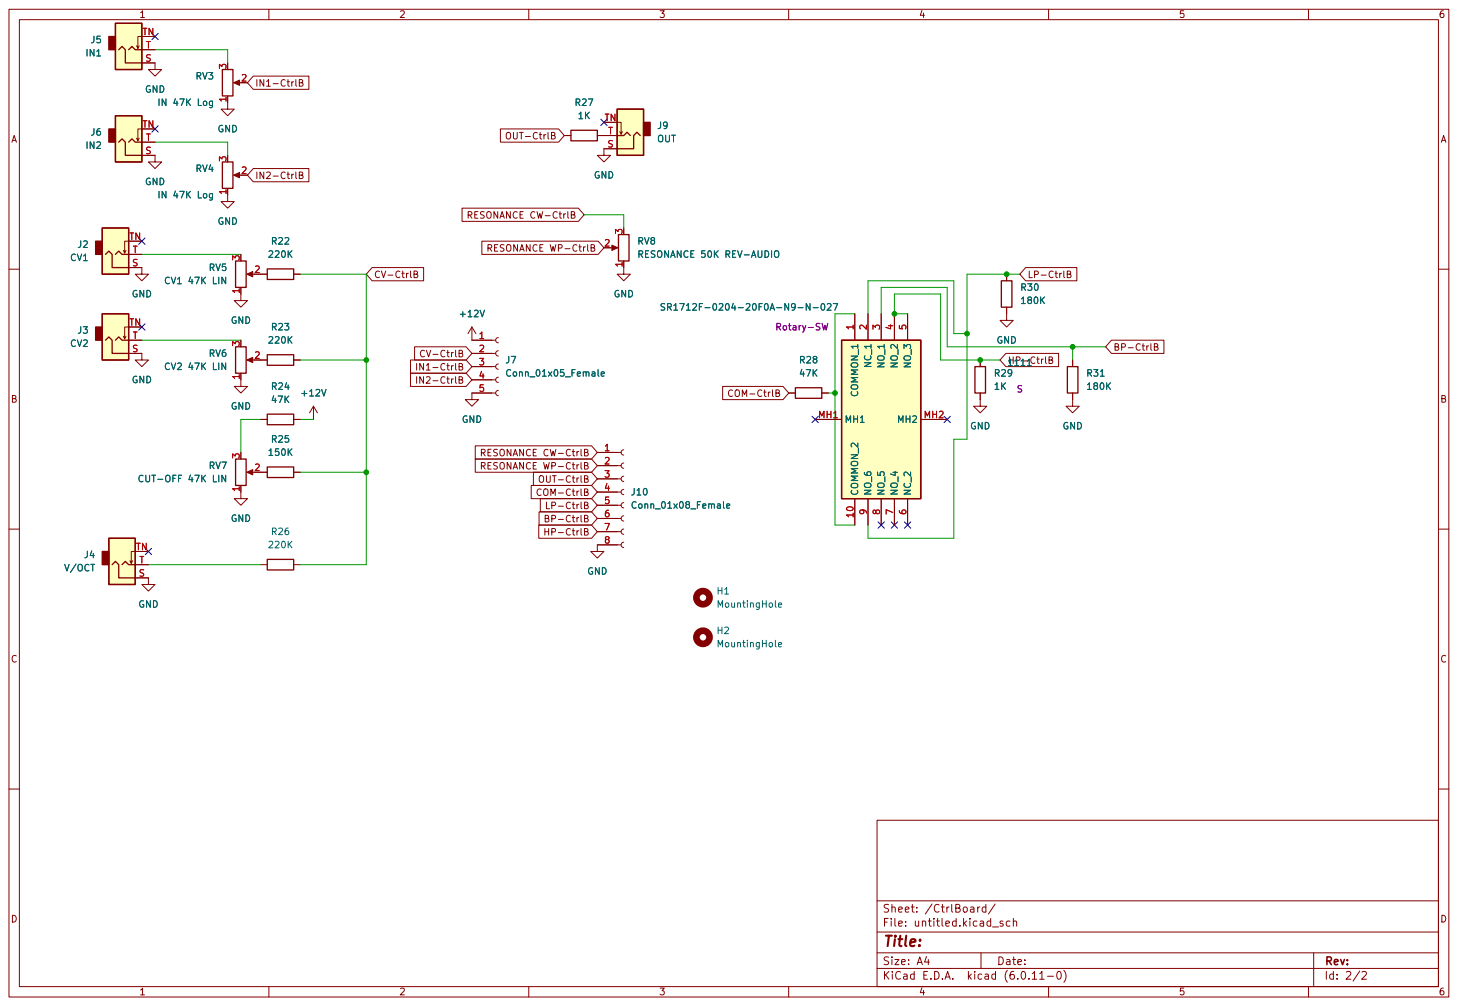
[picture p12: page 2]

RESONANCE CW-CtrlB OUT-CtrlB RESONANCE CW-CtrlB RESONANCE WP-CtrlB

3 RV7 CUT-OFF 47K LIN GND

BP-CtrlB HP-CtrlB COM-CtrlB RESONANCE WP-CtrlB OUT-CtrlB

Id: 2/2 Title: File: untitled.kicad_sch Sheet: /CtrlBoard/

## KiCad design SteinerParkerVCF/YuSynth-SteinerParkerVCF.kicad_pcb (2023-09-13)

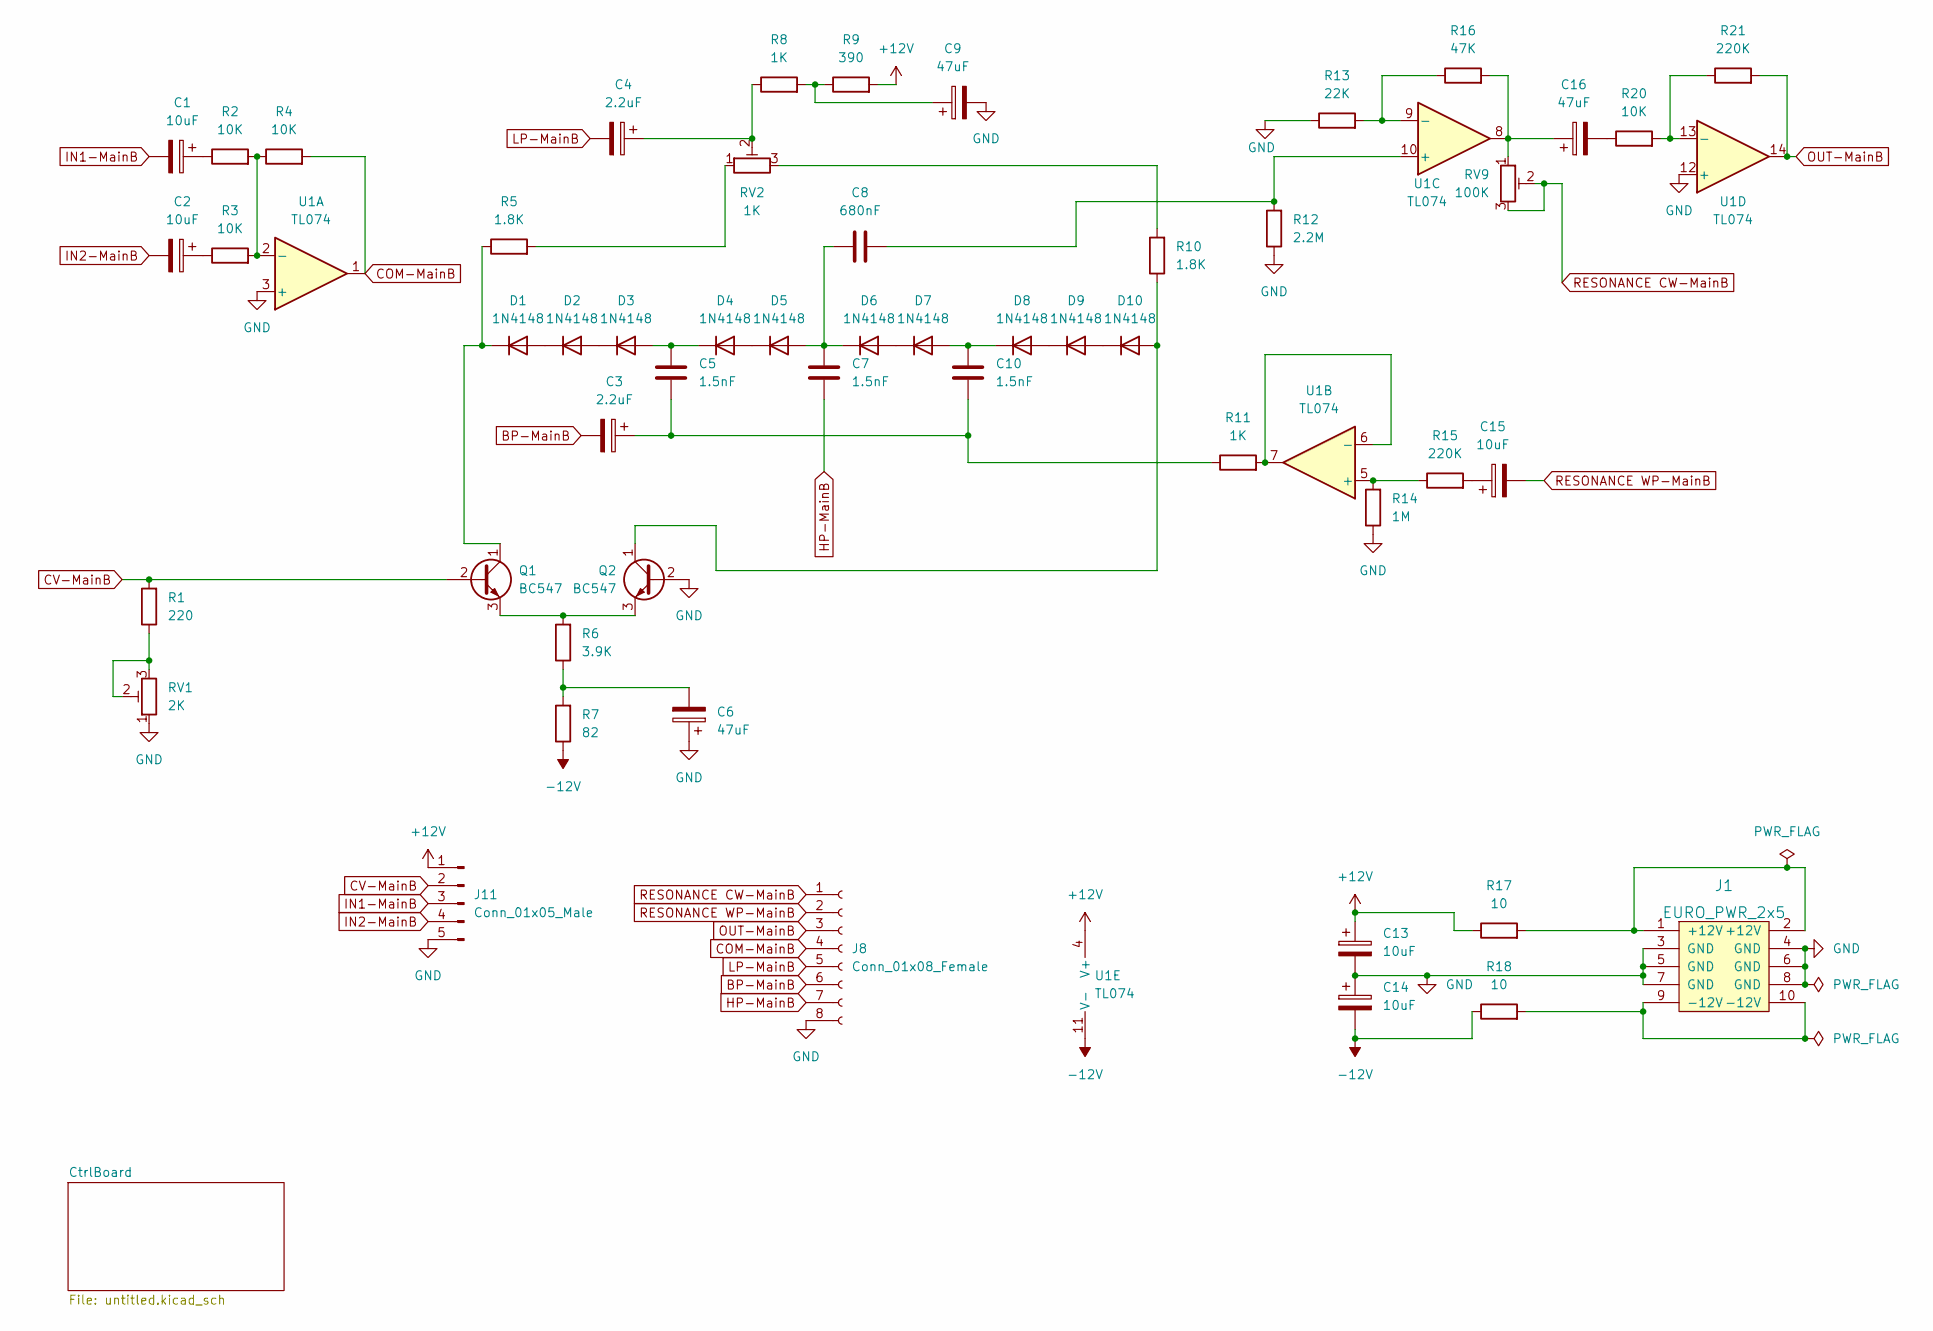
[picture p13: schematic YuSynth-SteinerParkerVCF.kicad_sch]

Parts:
C1, C2, C13, C14, C15: 10uF; CP_Radial_D5.0mm_P2.00mm
C3, C4: 2.2uF; CP_Radial_D5.0mm_P2.00mm
C5, C7, C10: 1.5nF; C_Rect_L7.0mm_W3.5mm_P5.00mm
C6, C9, C16: 47uF; CP_Radial_D5.0mm_P2.00mm
C8: 680nF; C_Rect_L7.0mm_W3.5mm_P5.00mm
D1, D2, D3, D4, D5, D6, D7, D8, D9, D10: 1N4148; D_DO-35_SOD27_P7.62mm_Horizontal
J1: EURO_PWR_2x5; Eurorack_power_header
J8: Conn_01x08_Female; PinHeader_1x08_P2.54mm_Vertical
J11: Conn_01x05_Male; PinHeader_1x05_P2.54mm_Vertical
Q1, Q2: BC547; TO-92_HandSolder
R1: 220; R_Axial_DIN0207_L6.3mm_D2.5mm_P5.08mm_Vertical
R2, R3, R4, R20: 10K; R_Axial_DIN0207_L6.3mm_D2.5mm_P5.08mm_Vertical
R5, R10: 1.8K; R_Axial_DIN0207_L6.3mm_D2.5mm_P5.08mm_Vertical
R6: 3.9K; R_Axial_DIN0207_L6.3mm_D2.5mm_P5.08mm_Vertical
R7: 82; R_Axial_DIN0207_L6.3mm_D2.5mm_P5.08mm_Vertical
R8, R11: 1K; R_Axial_DIN0207_L6.3mm_D2.5mm_P5.08mm_Vertical
R9: 390; R_Axial_DIN0207_L6.3mm_D2.5mm_P5.08mm_Vertical
R12: 2.2M; R_Axial_DIN0207_L6.3mm_D2.5mm_P5.08mm_Vertical
R13: 22K; R_Axial_DIN0207_L6.3mm_D2.5mm_P5.08mm_Vertical
R14: 1M; R_Axial_DIN0207_L6.3mm_D2.5mm_P5.08mm_Vertical
R15, R21: 220K; R_Axial_DIN0207_L6.3mm_D2.5mm_P5.08mm_Vertical
R16: 47K; R_Axial_DIN0207_L6.3mm_D2.5mm_P5.08mm_Vertical
R17, R18: 10; R_Axial_DIN0207_L6.3mm_D2.5mm_P5.08mm_Vertical
RV1: 2K; Potentiometer_Bourns_3266Y_Vertical
RV2: 1K; Potentiometer_Bourns_3266Y_Vertical
RV9: 100K; Potentiometer_Bourns_3266Y_Vertical
U1: TL074; DIP-14_W7.62mm_LongPads

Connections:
+12V: C13.1, J11.1, R9.2, R17.1, U1.4 (V+); also elsewhere on the board
-12V: C14.2, R7.1, R18.1, U1.11 (V-)
BP-MainB: C3.2, J8.6
COM-MainB: J8.4, R4.2, U1.1
CV-MainB: J11.2, Q1.2 (B), R1.2
GND: C6.1, C9.2, C13.2, C14.1, J1.3 (GND), J1.4 (GND), J1.5 (GND), J1.6 (GND), J1.7 (GND), J1.8 (GND), J8.8, J11.5, Q2.2 (B), R12.1, R13.1, R14.1, RV1.1, U1.3 (+), U1.12 (+); also elsewhere on the board
HP-MainB: C7.2, J8.7
IN1-MainB: C1.2, J11.3
IN2-MainB: C2.2, J11.4
LP-MainB: C4.2, J8.5
unnamed: C1.1, R2.1
unnamed: C2.1, R3.1
unnamed: C4.1, R8.1, RV2.2
unnamed: C5.1, D3.2 (A), D4.1 (K)
unnamed: C6.2, R6.1, R7.2
unnamed: C7.1, C8.1, D5.2 (A), D6.1 (K)
unnamed: C8.2, R12.2, U1.10 (+)
unnamed: C9.1, R8.2, R9.1
unnamed: C10.1, D7.2 (A), D8.1 (K)
unnamed: C3.1, C5.2, C10.2, R11.1
unnamed: C15.1, R15.2
unnamed: C16.1, R16.2, RV9.1, U1.8
unnamed: C16.2, R20.1
unnamed: D1.1 (K), Q1.1 (C), R5.1
unnamed: D1.2 (A), D2.1 (K)
unnamed: D2.2 (A), D3.1 (K)
unnamed: D4.2 (A), D5.1 (K)
unnamed: D6.2 (A), D7.1 (K)
unnamed: D8.2 (A), D9.1 (K)
unnamed: D9.2 (A), D10.1 (K)
unnamed 37: D10.2 (A), Q2.1 (C), R10.1; also elsewhere on the board
unnamed: J1.1 (+12V), J1.2 (+12V), R17.2
unnamed: J1.9 (-12V), J1.10 (-12V), R18.2
unnamed 46: Q1.3 (E), Q2.3 (E), R6.2; also elsewhere on the board
unnamed: R1.1, RV1.2, RV1.3
unnamed: R2.2, R3.2, R4.1, U1.2 (-)
unnamed: R5.2, RV2.1
unnamed: R10.2, RV2.3
unnamed: R11.2, U1.6 (-), U1.7
unnamed: R13.2, R16.1, U1.9 (-)
unnamed: R14.2, R15.1, U1.5 (+)
unnamed: R20.2, R21.1, U1.13 (-)
OUT-MainB: J8.3, R21.2, U1.14
RESONANCE CW-MainB: J8.1, RV9.2, RV9.3
RESONANCE WP-MainB: C15.2, J8.2

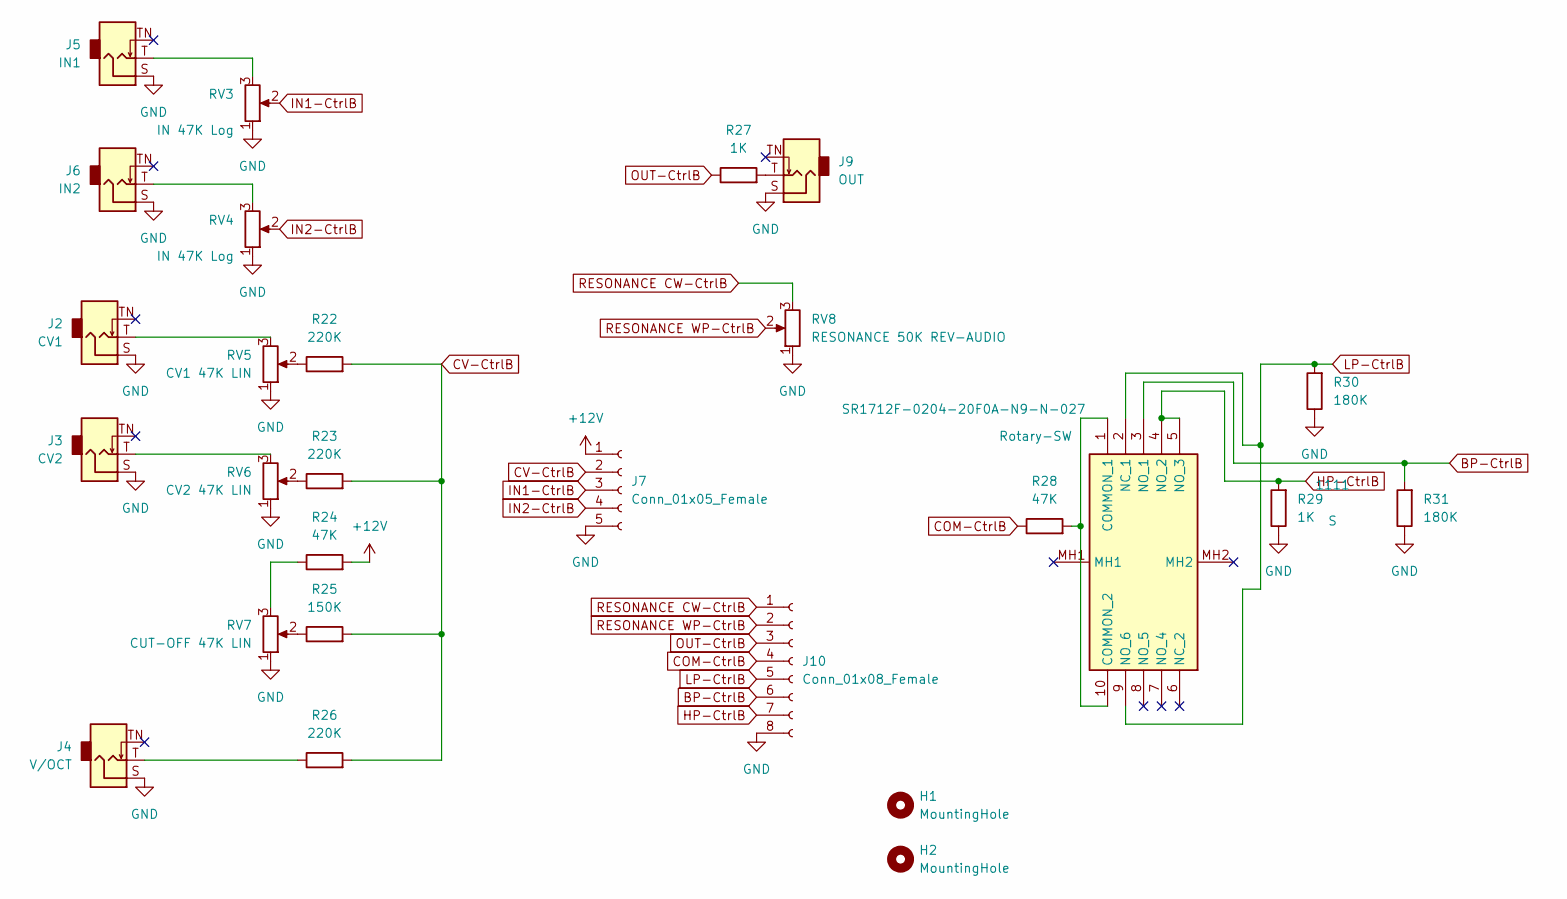
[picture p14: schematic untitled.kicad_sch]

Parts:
1111: SR1712F-0204-20F0A-N9-N-027; SR1712F020420F0AN9N027; Mouser Part Number 105-SR1712F-24NS
H1, H2: MountingHole; MountingHole_3.2mm_M3
J2: CV1; Jack_3.5mm_QingPu_WQP-PJ398SM_Vertical
J3: CV2; Jack_3.5mm_QingPu_WQP-PJ398SM_Vertical
J4: V/OCT; Jack_3.5mm_QingPu_WQP-PJ398SM_Vertical
J5: IN1; Jack_3.5mm_QingPu_WQP-PJ398SM_Vertical
J6: IN2; Jack_3.5mm_QingPu_WQP-PJ398SM_Vertical
J7: Conn_01x05_Female; PinHeader_1x05_P2.54mm_Vertical
J9: OUT; Jack_3.5mm_QingPu_WQP-PJ398SM_Vertical
J10: Conn_01x08_Female; PinHeader_1x08_P2.54mm_Vertical
R22, R23, R26: 220K; R_Axial_DIN0207_L6.3mm_D2.5mm_P5.08mm_Vertical
R24, R28: 47K; R_Axial_DIN0207_L6.3mm_D2.5mm_P5.08mm_Vertical
R25: 150K; R_Axial_DIN0207_L6.3mm_D2.5mm_P5.08mm_Vertical
R27, R29: 1K; R_Axial_DIN0207_L6.3mm_D2.5mm_P5.08mm_Vertical
R30, R31: 180K; R_Axial_DIN0207_L6.3mm_D2.5mm_P5.08mm_Vertical
RV3, RV4: IN 47K Log; Potentiometer_Alpha_RD901F-40-00D_Single_Vertical
RV5: CV1 47K LIN; Potentiometer_Alpha_RD901F-40-00D_Single_Vertical
RV6: CV2 47K LIN; Potentiometer_Alpha_RD901F-40-00D_Single_Vertical
RV7: CUT-OFF 47K LIN; Potentiometer_Alpha_RD901F-40-00D_Single_Vertical
RV8: RESONANCE 50K REV-AUDIO; Potentiometer_Alpha_RD901F-40-00D_Single_Vertical

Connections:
+12V: J7.1, R24.2; also elsewhere on the board
BP-CtrlB: 1111.3 (NO_1), J10.6, R31.2
COM-CtrlB: J10.4, R28.1
CV-CtrlB: J7.2, R22.2, R23.2, R25.2, R26.2
GND: J2.S, J3.S, J4.S, J5.S, J6.S, J7.5, J9.S, J10.8, R29.1, R30.1, R31.1, RV3.1, RV4.1, RV5.1, RV6.1, RV7.1, RV8.1; also elsewhere on the board
HP-CtrlB: 1111.4 (NO_2), 1111.5 (NO_3), J10.7, R29.2
IN1-CtrlB: J7.3, RV3.2
IN2-CtrlB: J7.4, RV4.2
LP-CtrlB: 1111.2 (NC_1), 1111.9 (NO_6), J10.5, R30.2
unnamed: J2.T, RV5.3
unnamed: J3.T, RV6.3
unnamed: J4.T, R26.1
unnamed: J5.T, RV3.3
unnamed: J6.T, RV4.3
unnamed: J9.T, R27.2
unnamed: R22.1, RV5.2
unnamed: R23.1, RV6.2
unnamed: R24.1, RV7.3
unnamed: R25.1, RV7.2
unnamed: 1111.1 (COMMON_1), 1111.10 (COMMON_2), R28.2
OUT-CtrlB: J10.3, R27.1
RESONANCE CW-CtrlB: J10.1, RV8.3
RESONANCE WP-CtrlB: J10.2, RV8.2

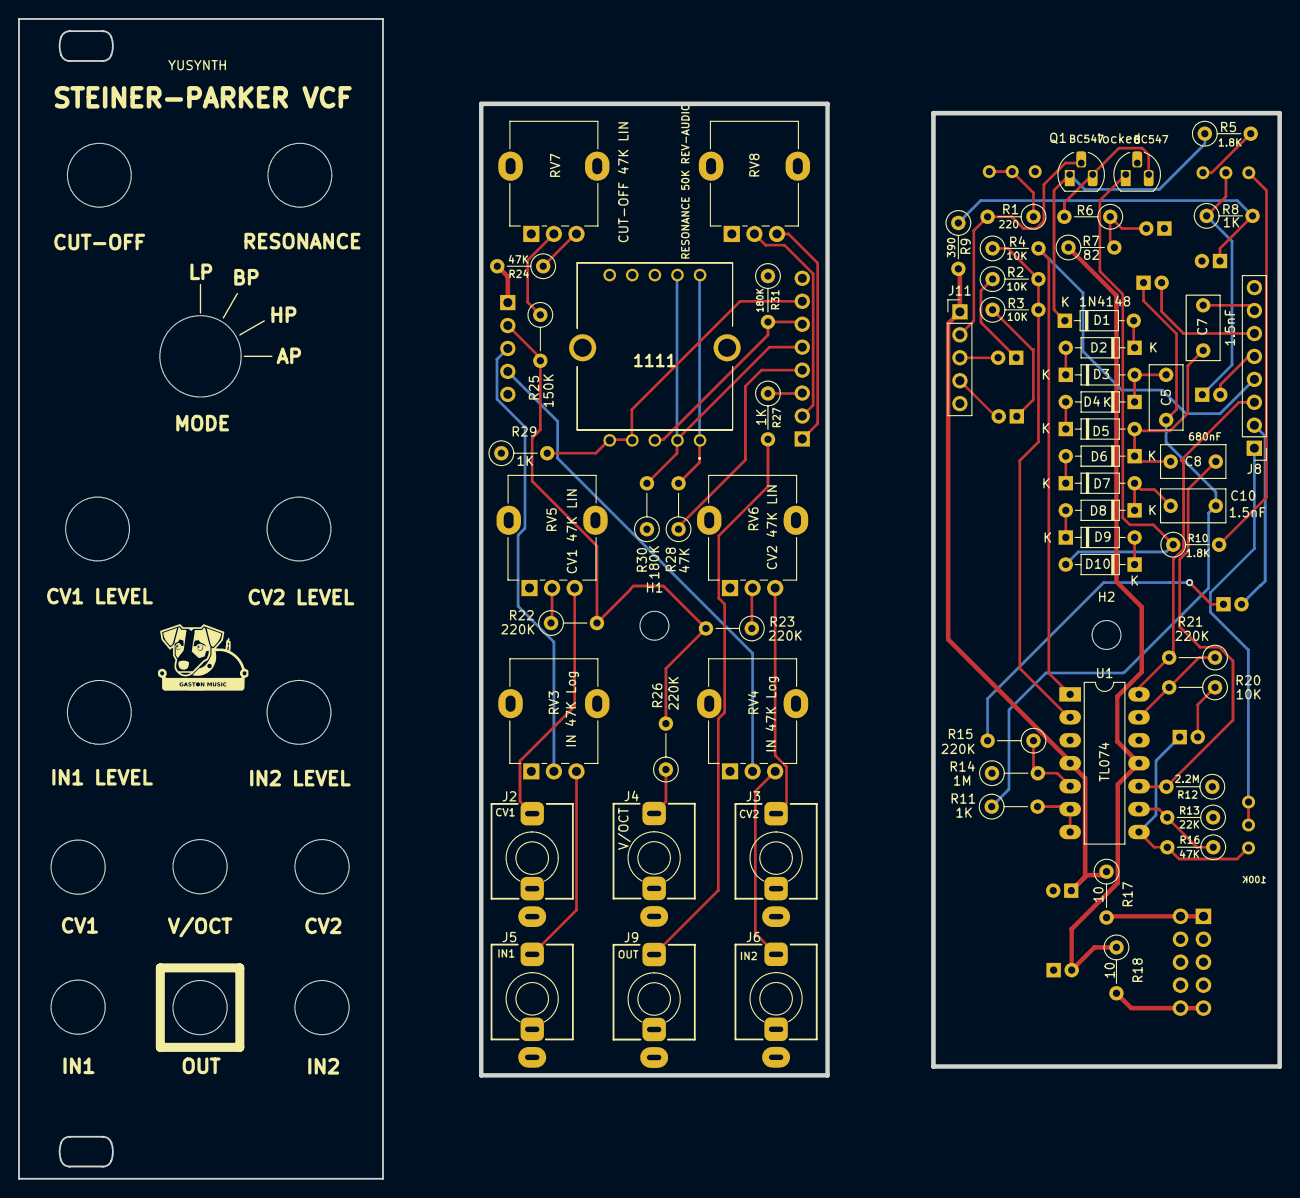
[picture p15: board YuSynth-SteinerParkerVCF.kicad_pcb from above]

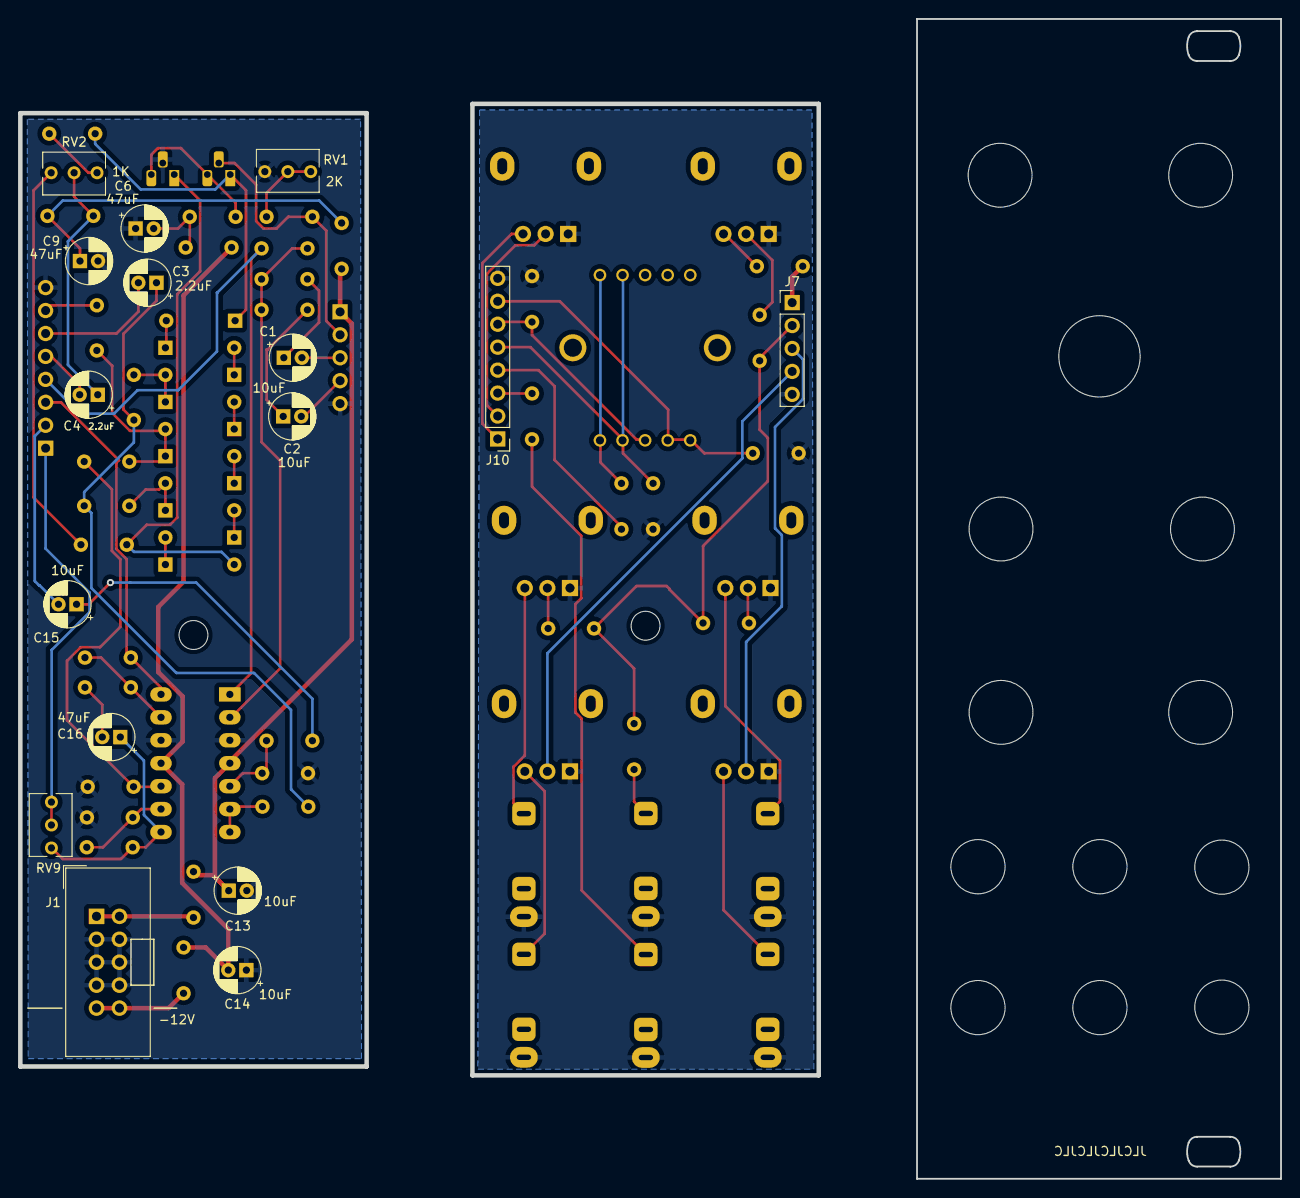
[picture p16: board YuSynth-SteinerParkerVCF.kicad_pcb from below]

Board: 2 copper layers, 139.6 x 128.4 mm, 80 parts (16 on the bottom side), 66 nets.

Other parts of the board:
locked: BC547; TO-92_HandSolder

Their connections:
GND: locked.2 (B); also elsewhere on the board
unnamed 37: locked.1 (C); also elsewhere on the board
unnamed 46: locked.3 (E); also elsewhere on the board

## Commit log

2023-09-13 modif pcb
    [YuSynth-SteinerParkerVCF.kicad_pcb, YuSynth-SteinerParkerVCF.kicad_sch, untitled.kicad_sch]
2023-10-20 add pdf
    [YuSynth-SteinerParkerVCF.csv]
